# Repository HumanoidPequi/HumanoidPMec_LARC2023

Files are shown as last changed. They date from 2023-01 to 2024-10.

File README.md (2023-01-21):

# Humanoid_LARC2023
Pequi Mecânico - Humanoid soccer LARC 2023

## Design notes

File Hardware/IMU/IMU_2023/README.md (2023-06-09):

# Esquemáticos e informações sobre os IMUS
 As bibliotecas Podem ser encontradas na própria Arduino IDE
- Para o MPU6050: FastIMU
- Para o BNO080: SparkFun BNO080 Cortex Based IMU

## Lembrando que o as pinos padrão da ESP para I2C são:
### D21 - SDA
### D22 - SCL



## Esquemáticos (BNO080 e MPU6050)


# ...[Atenção]...
caso seja encontrado problemas com a utilização do MPU6050, adicione resistores de 10k nos sinais SDA e SCL em configuração pull-up (resistores ligados diretamente no positivo [3.3V] de alimentação)

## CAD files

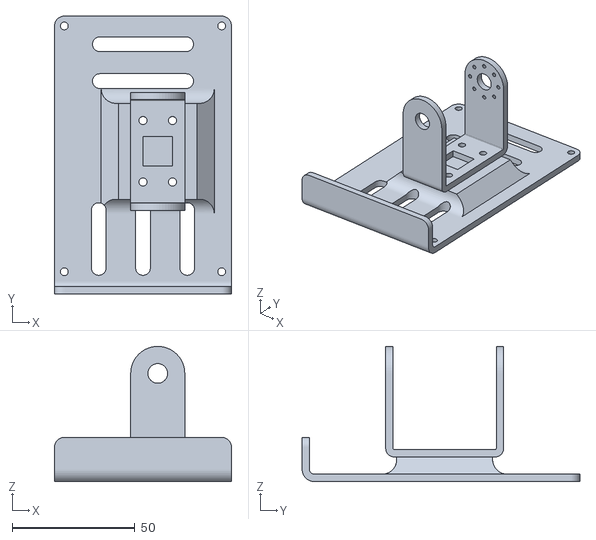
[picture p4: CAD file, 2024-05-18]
Simulação/Martha_ws/src/martha_description/meshes/pe_direito_1.stl
72.0 x 113.0 x 55.0

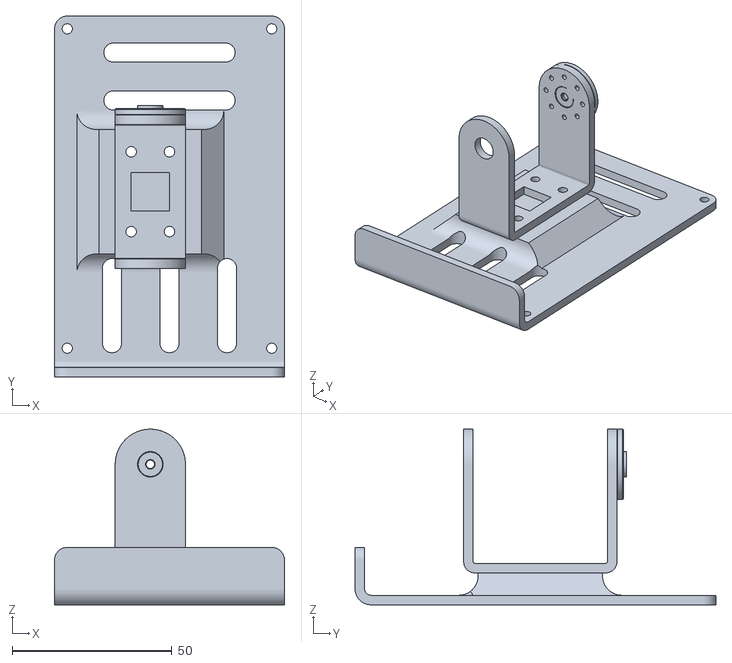
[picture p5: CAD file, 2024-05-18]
Simulação/Martha_ws/src/martha_description/meshes/pe_esquerdo_1.stl
72.0 x 113.0 x 55.0

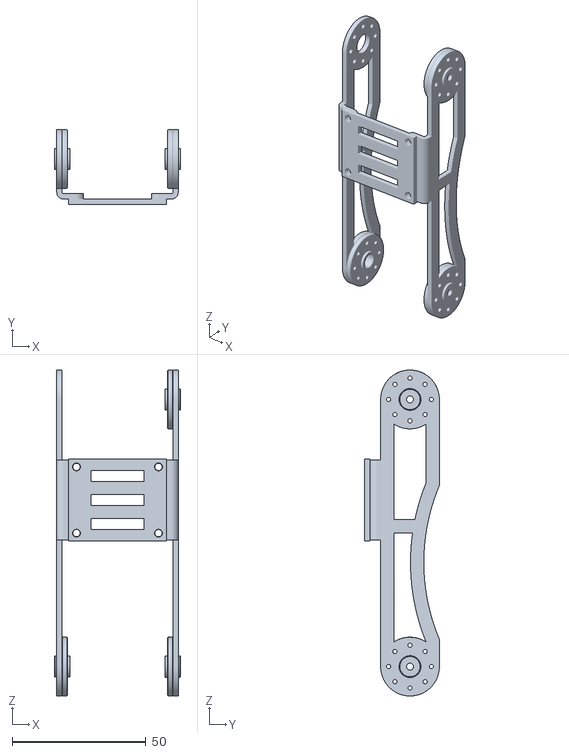
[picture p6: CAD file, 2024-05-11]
Simulação/Martha_ws/src/martha_description/meshes/canela_direita_2_1.stl
47.2 x 28.0 x 122.0

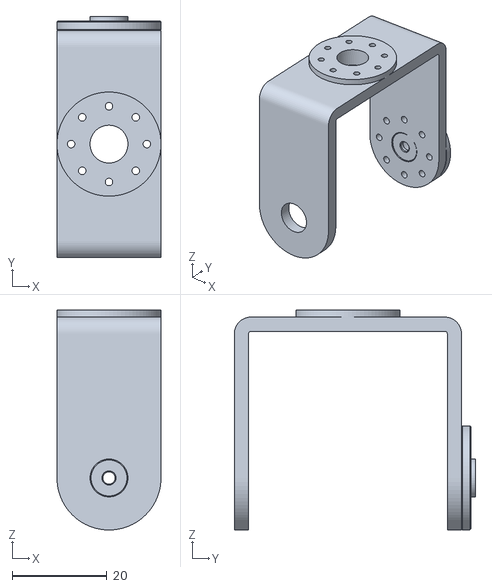
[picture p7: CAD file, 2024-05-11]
Simulação/Martha_ws/src/martha_description/meshes/quadril_direito_1.stl
22.0 x 51.0 x 46.5

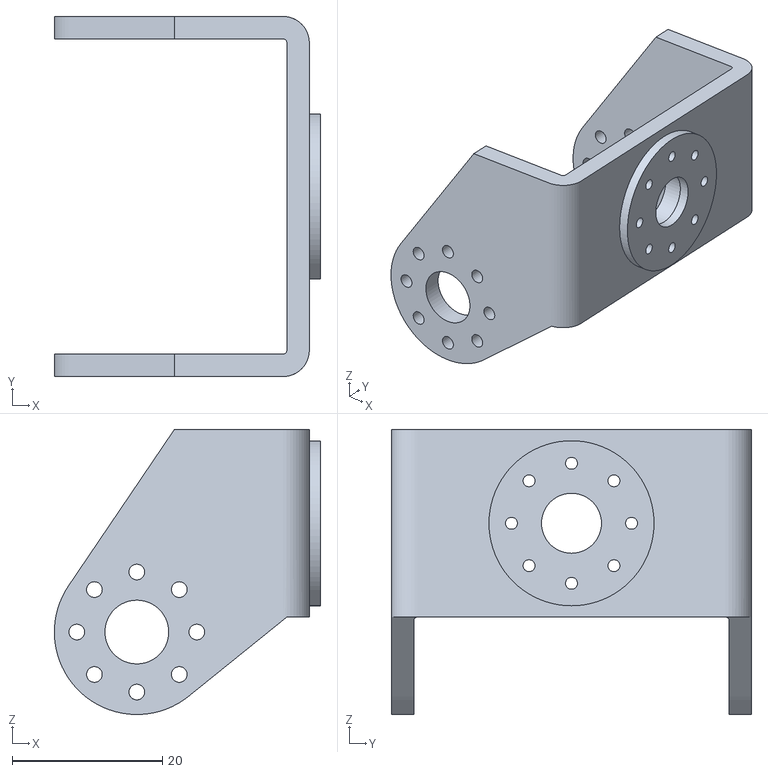
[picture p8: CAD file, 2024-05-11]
Simulação/Martha_ws/src/martha_description/meshes/ombro_direito_1.stl
35.5 x 48.0 x 38.0

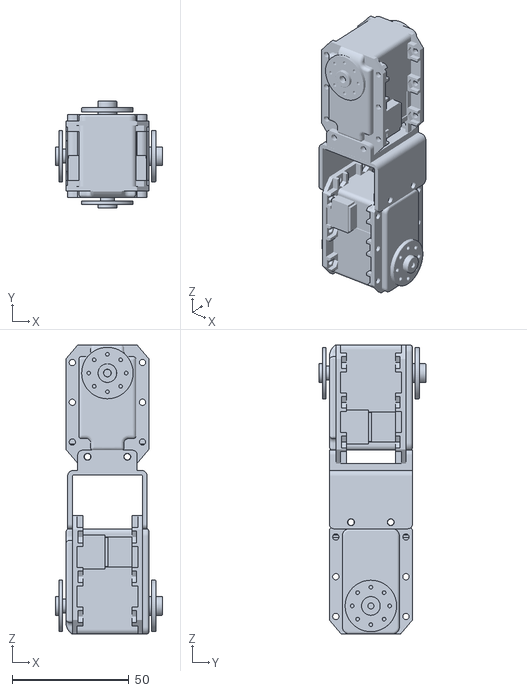
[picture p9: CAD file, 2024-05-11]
Simulação/Martha_ws/src/martha_description/meshes/braco_direito_1.stl
45.8 x 45.9 x 123.6

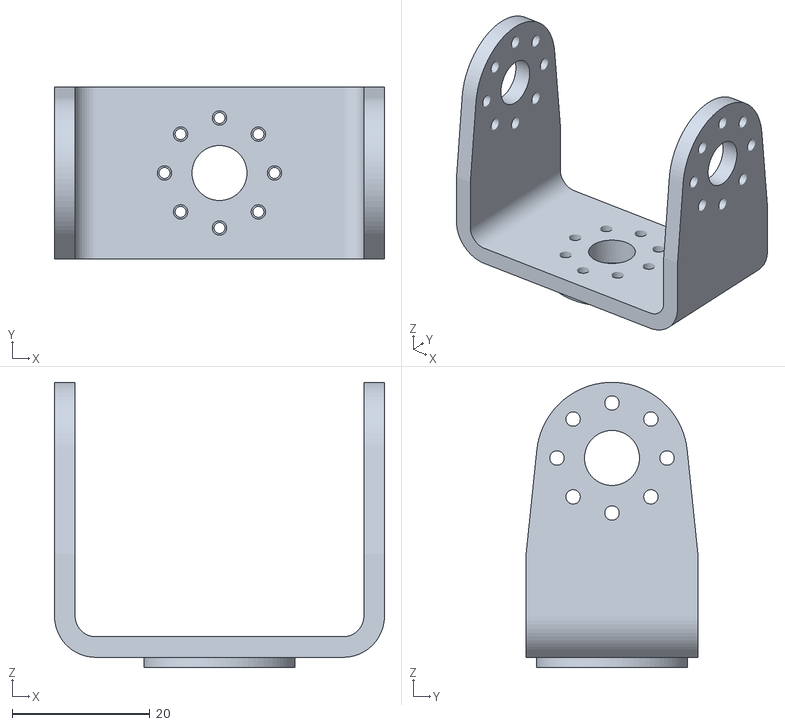
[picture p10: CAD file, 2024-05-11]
Simulação/Martha_ws/src/martha_description/meshes/pescoco_1.stl
48.0 x 25.0 x 41.5

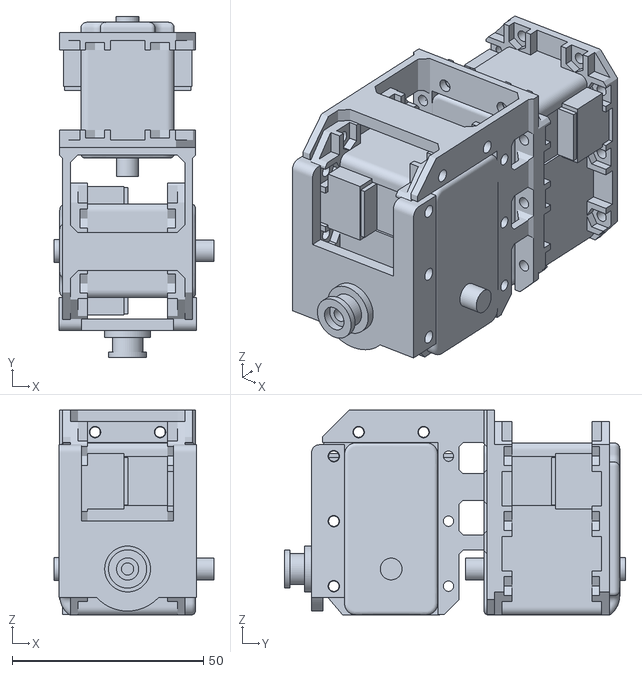
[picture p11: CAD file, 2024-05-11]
Simulação/Martha_ws/src/martha_description/meshes/calcanhar_esquerdo_1.stl
41.8 x 89.2 x 53.5

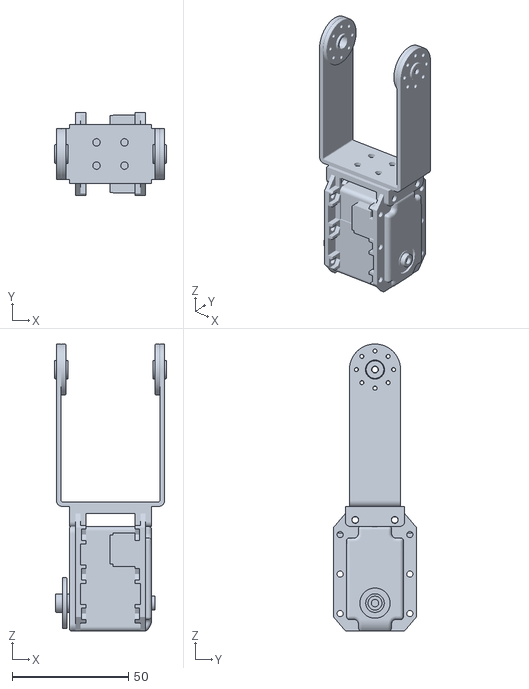
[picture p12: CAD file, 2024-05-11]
Simulação/Martha_ws/src/martha_description/meshes/canela_esquerda_1.stl
48.2 x 35.6 x 123.5

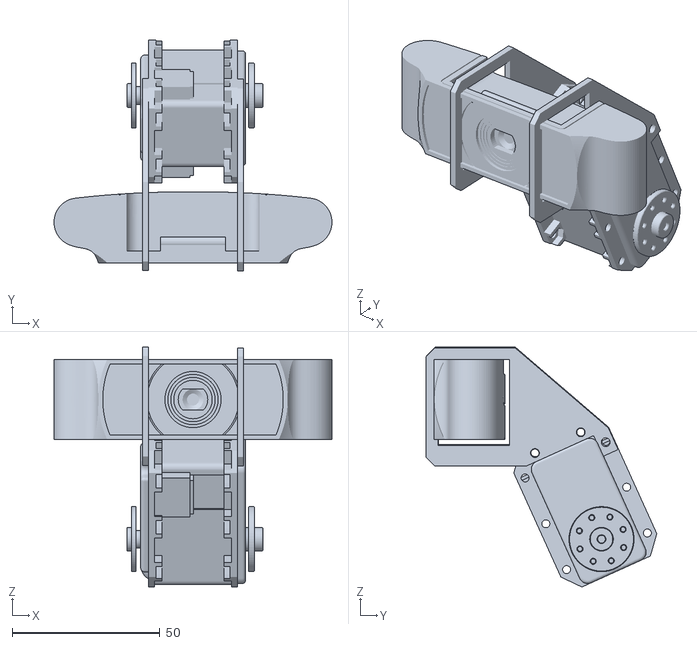
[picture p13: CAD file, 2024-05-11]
Simulação/Martha_ws/src/martha_description/meshes/cabeca_1.stl
94.0 x 78.0 x 81.1

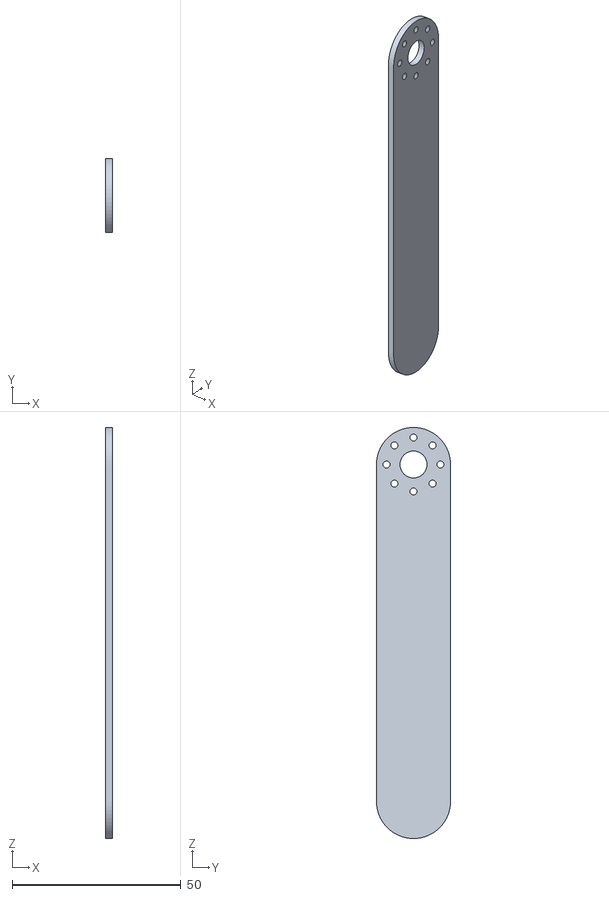
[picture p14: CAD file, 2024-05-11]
Simulação/Martha_ws/src/martha_description/meshes/mao_esquerda_1.stl
2.00 x 22.0 x 122.0

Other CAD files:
Simulação/Martha_ws/src/martha_description/meshes/canela_esquerda_2_1.stl
Simulação/Martha_ws/src/martha_description/meshes/ombro_esquerdo_1.stl
Simulação/Martha_ws/src/martha_description/meshes/braco_esquerdo_1.stl
Simulação/Martha_ws/src/martha_description/meshes/quadril_esquerdo_1.stl
Simulação/Martha_ws/src/martha_description/meshes/canela_direita_1.stl
Simulação/Martha_ws/src/martha_description/meshes/coxa_esquerda_1.stl
Simulação/Martha_ws/src/martha_description/meshes/calcanhar_direito_1.stl
Simulação/Martha_ws/src/martha_description/meshes/coxa_direita_1.stl
Simulação/Martha_ws/src/martha_description/meshes/mao_direita_1.stl

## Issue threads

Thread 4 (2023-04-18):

Ball Tracking

dimitriasilveria, 2023-04-18:

dimitriasilveria, 2023-04-18:
- [ ] Train Yolo object detection
- [ ] Use box coordinates to estimate xy ball position
- [ ] Calculate the necessary angular displacement to align the camera center with the ball
- [ ] Send this angle to the servos via ros
- [ ] Use optical flow to ensure the ball keeps aligned
- [ ] Read head pitch angle from IMU information (via ROS)
- [ ] Distance estimation

dimitriasilveria, 2023-04-23:
<!-- Failed to upload "robocup_book.pdf" -->

dimitriasilveria, 2023-05-06:
@andrecaraiba we need the IMU readings as soon as possible, please

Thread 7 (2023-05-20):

Rosserial

lucasolives, 2023-05-20:

lucasolives, 2023-05-20:
1. Open up terminal and type: `roscore`
2. In a new terminal type: `rosrun rosserial_arduino serial_node.py _port:=/dev/ttyUSB0`
3. Type `rostopic list` to make sure that everything is running

lucasolives, 2023-05-20:
**[ERROR] [1684614705.969329]: Unable to sync with device; possible link problem or link software version mismatch such as hydro rosserial_python with groovy Arduino**

lucasolives, 2023-05-20:
Possible solution:
If rebuilding isn't an option you can add the definitions manually. On the arduino side you'll have a ros_lib folder. You have two sub directories you need to change.

The first is ./ros/node_handle.h. At the top of the file you'll see a few protocol versions defined as const uint8_t. Add in the version id for noetic as const uint8_t PROTOCOL_VER6 = 0xfa; then change the line that states what version should be used. const uint8_t PROTOCOL_VER = PROTOCOL_VER6;.

Lastly, you just need to make this same change in ./ros_lib/ros/node_handle.h

lucasolives, 2023-05-21:
The code **controle_baixo_nível.ino** is being developed, so it has some things that need to be fixed. 1 - `servo_cb()` is able to receive only one angle when it should get two.
Possible solution: Create a `custom_msg` package that contains two UInt16 values.

andrecaraiba, 2023-06-01:
This tutorial solved the problem: https://answers.ros.org/question/394805/esp32-keep-rebooting-with-rosserial/

Closed 2023-06-09.

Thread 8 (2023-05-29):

Trouble with Dynamixel signal

alvinolima50, 2023-05-29:

alvinolima50, 2023-05-29:
What can it be?
The cable impedance is different from the dynamixel input impedance, causing a reflection of the signal interfering with the input signal.

Options to solve the problem: avoid this reflection!

- [ ] level shifter position change
- [ ] Add Diode 5V
- [ ]

andrecaraiba, 2023-06-01:
Possible cause: Incompatibility between the Dynamixel firmware and the Dynamixel2Arduino library. To resolve the issue, it was necessary to change the firmware version from 45 to 40. You can use this reference to update the firmware version by following the steps outlined in Wizard 2.0: [Update firmware version](https://m.youtube.com/watch?v=aVZytXRc_r8).

Additionally, it has been discovered that the signal reflection is actually a return packet containing status information that the Dynamixel returns. You can find more details about this in the [Dynamixel Protocol 1.0 documentation](https://emanual.robotis.com/docs/en/dxl/protocol1/).

Furthermore, for the Dynamixel to function properly, the microcontroller needs to receive these return packet information. This requires a communication circuit between the Dynamixel and the microcontroller. You can refer to the [MX-28 documentation documentation](https://emanual.robotis.com/docs/en/dxl/mx/mx-28/), the circuit is also located in the hardware folder of the repository.

Closed 2023-06-09.

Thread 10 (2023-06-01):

2 Dynamixel strugling to execute different angles

lucasolives, 2023-06-01:

lucasolives, 2023-06-01:
Executing the `codigo_baixo_nivel.ino` in order to send different angles to each dynamixel, the servo was receiving those angles and executed in the first time that i published some data.  In the following publications, the dynamixels stoped to answer the command correctly and made only little movements every time i sent a new angle.

lucasolives, 2023-06-01:
Next questions:
1 - That delay will get us in trouble when the high level is executing by the fact that it stops the program during the time set? Even though it's a small delay?
2 - Apparently there's a function in ros that works kinda like a timer. I didn't go deeper in the subject but the benefit would be that this function wouldn't stop the entire code, but just that process. That way, it would be possible to run another things while the timer is waiting. Is it a better option? (Do some research about `ros::Timer`, `ros::Duration` and the function `now()`)

lucasolives, 2023-06-01:
Structure of ros command to send a UInt16MultiArray type of message(in our case where the topic is servo and we're sending two angles): `rostopic pub servo std_msgs/UInt16MultiArray "data: [**angle1**, **angle2**]"`

Closed 2023-06-09.

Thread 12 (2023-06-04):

Imu

dimitriasilveria, 2023-06-04:

dimitriasilveria, 2023-06-04:
Bno uses I2C protocol. Here is a brief explanation of this protocol: https://www.circuitbasics.com/basics-of-the-i2c-communication-protocol/

dimitriasilveria, 2023-06-04:
esp i2c default pinout: https://randomnerdtutorials.com/esp32-i2c-communication-arduino-ide/#:~:text=When%20using%20the%20ESP32%20with,to%20use%20any%20other%20pins.

dimitriasilveria, 2023-06-04:
bno: https://learn.sparkfun.com/tutorials/qwiic-vr-imu-bno080-hookup-guide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

dimitriasilveria, 2023-06-04:
esp pinout: imagem: https://live.staticflickr.com/4764/40089095211_ec1fee0087_b.jpg

dimitriasilveria, 2023-06-04:
bno hardware description: https://learn.sparkfun.com/tutorials/qwiic-vr-imu-bno080-hookup-guide/all#hardware-assembly

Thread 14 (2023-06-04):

Install ROS jetson tx2

dimitriasilveria, 2023-06-04:
We decide to use ros noetic because we don't have enough knowledge to use microros

dimitriasilveria, 2023-06-04:
Nvidia ros containers: https://github.com/dusty-nv/jetson-containers/tree/master

dimitriasilveria, 2023-06-04:
We could not install ros container because there was no space left on the device. Possible solution:
https://forums.developer.nvidia.com/t/increase-storage-space-of-jetson-tx2-dev-kit-using-sd-card/76872

dimitriasilveria, 2023-06-09:
I am closing this issue because I opened another one in another project

Closed 2023-06-09.

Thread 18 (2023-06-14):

rosserial inside docker container

dimitriasilveria, 2023-06-14:

dimitriasilveria, 2023-06-14:
possible link problem or link software version mismatch such as hydro rosserial_python with groovy Arduino

dimitriasilveria, 2023-06-14:
One possible solution: https://www.hostinger.com.br/tutoriais/arquivo-sudoers

andrecaraiba, 2023-06-15:
possible solution: https://www.homeautomationguy.io/blog/docker-tips/accessing-usb-devices-from-docker-containers

lucasolives, 2023-06-17:
sudo docker build -t teste_ino --build-arg CACHEBUST=$(date +%s) .

sudo docker run -it --privileged -v /dev:/dev --name teste_ino teste_ino bash

lucasolives, 2023-06-19:
Error: Cannot open /dev/ttyUSB0: Permission denied
Solution:
sudo su
//type your password
cd /
cd dev
chown username ttyUSB0

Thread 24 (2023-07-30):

Using two serial ports with esp32

lucasolives, 2023-07-30:

lucasolives, 2023-07-31:
Using the circuit attached to this comment, we tried to use two serial ports in esp32 in order to put one leg on each serial port.

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

Making some tests,

lucasolives, 2023-07-31:
Making some tests, we noticed that esp32 wasn't sending data to both port serials[Serial1(TX0, RX0) e Serial2(TX2, RX2)]. We tried some strategys to solve this problem:

- [ ] Changing HardwareSerial.cpp as the following video told to: [](https://emanual.robotis.com/docs/en/dxl/mx/mx-28/)

- [ ] Use SoftwareSerial with esp32, but aparently it's impossible since esp32 no longer has support to this library.

- [ ] Using the Esp32Software serial. Also didn't work, even though we move uart1 to another pins recommended.

- [ ] Making some research, we found out that esp32 has some gpio's not recommended to use for serial communications, since it's used for flash memory. Aparently, to use uart1, it's necessary the reassignment of pins: [](https://microcontrollerslab.com/esp32-uart-communication-pins-example/) Obs: It's weird, because our esp doesn't have GPIO9 and 10.

- [ ] We found out a repository that changed the dynamixel2arduino library to improve serial communication with esp32 in order to make it easier using 2 serial ports, but also didnt't work: https://github.com/maehem/ESP32-Dynamixel/tree/master

lucasolives, 2023-07-31:
Pinout Esp32:

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

lucasolives, 2023-08-04:
Utilizar preferencialmente as GPIOs:
tx -> 0,2,12,13,14,15,16,17,25,26,27
rx -> 0,2,12,13,14,15,16,17,25,26,27,32,33,34,36,39

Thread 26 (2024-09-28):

Finalização do projeto estrutural

lucasolives, 2024-09-28:
(adicionar @ do marcelo) relatou que a Marta estava com massa discrepante, portanto foi necessário pesar individualmente peças de alumínio.

lucasolives, 2024-09-28:
(adicionar @ do davi aqui) e (adicionar @ do ólives) pesaram componentes. Seguem esses dados:
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
[Página do notion](https://www.notion.so/Pe-as-marcelo-10b21c3dc3788095a0e2e396b4c24415?pvs=4)

lucasolives, 2024-09-28:
Fez-se necessário modelar algumas peças para 3D devido a grande massa das peças, além de ajustar algumas.

- [ ] Inserir insertos em bases genéricas
- [ ] Alterar base da cabeça para 3D
- [ ] Alterar topo da estrurura para 3D
- [ ] Alterar frente inferir para 3D com filamento flexível
- [ ] Alterar peças traseiras para proteger botões

lucasolives, 2024-09-28:
Retiramos estrutura externa da NUC para diminuir o peso geral. Faz-se necessário estrutura 3D para protegê-la na parte superior:
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

- [ ] Criação de estrutura superior da NUC

lucasolives, 2024-09-28:
Para imprimir pé da Marta com tamanho máximo, deve-se se limitar ao valor máximo que esta fómula entregar:
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
onde Hcom é a altura do centro de massa da Marta.

- [ ] Confecção de projeto do pé
- [ ] Definição do centro de massa da Marta
- [ ] Alterar para tamanho adequado
- [ ] Imprimir pé

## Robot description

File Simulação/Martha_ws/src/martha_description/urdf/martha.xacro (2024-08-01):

<?xml version="1.0" ?>
<robot name="martha" xmlns:xacro="http://www.ros.org/wiki/xacro">

<xacro:include filename="$(find martha_description)/urdf/materials.xacro" />
<xacro:include filename="$(find martha_description)/urdf/martha.trans" />
<xacro:include filename="$(find martha_description)/urdf/martha.gazebo" />
<xacro:include filename="$(find martha_description)/urdf/camera.xacro" />
<xacro:include filename="$(find martha_description)/urdf/IMU.xacro" />
<link name="base_link">
  <inertial>
    <origin xyz="-0.00023301230905643097 -0.008767749720889163 0.08499100214486582" rpy="0 0 0"/>
    <mass value="3.42324299"/>
    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
  </inertial>
  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
</link>

<link name="pescoco_1">
  <inertial>
    <origin xyz="-1.9023224968807838e-14 -8.281569874313277e-15 0.011104750965744897" rpy="0 0 0"/>
    <mass value="0.00752807"/>
    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
  </inertial>
  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
</link>

<link name="cabeca_1">
  <inertial>
    <origin xyz="-0.020728139217007956 -0.025090240858054468 0.029326950387914386" rpy="0 0 0"/>
    <mass value="0.16989203"/>
    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
  </inertial>
  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
</link>

<link name="ombro_esquerdo_1">
  <inertial>
    <origin xyz="0.0066866699241785454 2.0816681711721685e-17 -0.0032002556517522762" rpy="0 0 0"/>
    <mass value="0.00784823"/>
    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
  </inertial>
  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
</link>

<link name="ombro_direito_1">
  <inertial>
    <origin xyz="-0.006686669924178101 2.7755575615628914e-17 -0.0032002556517522207" rpy="0 0 0"/>
    <mass value="0.00784823"/>
    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
  </inertial>
  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
</link>

<link name="braco_esquerdo_1">
  <inertial>
    <origin xyz="2.1478896477855614e-05 0.020766946865101756 -0.04944488755371944" rpy="0 0 0"/>
    <mass value="0.24511984"/>
    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
  </inertial>
  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
</link>

<link name="braco_direito_1">
  <inertial>
    <origin xyz="2.1478896478493992e-05 0.02076694686510183 -0.04944488755371926" rpy="0 0 0"/>
    <mass value="0.24511984"/>
    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
  </inertial>
  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
</link>

<link name="mao_esquerda_1">
  <inertial>
    <origin xyz="0.0009999999999996262 1.8780116350924914e-14 -0.051558141367889714" rpy="0 0 0"/>
    <mass value="0.00500432"/>
    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
  </inertial>
  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
</link>

<link name="mao_direita_1">
  <inertial>
    <origin xyz="-0.0009999999999998066 -1.917389857997165e-14 -0.05155814136788935" rpy="0 0 0"/>
    <mass value="0.00500432"/>
    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
  </inertial>
  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
</link>

<link name="quadril_esquerdo_1">
  <inertial>
    <origin xyz="1.4314938123760612e-14 0.001988067036543086 -0.01689495335095707" rpy="0 0 0"/>
    <mass value="0.00770492"/>
    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
  </inertial>
  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
</link>

<link name="coxa_esquerda_1">
  <inertial>
    <origin xyz="1.4332694612498309e-05 -0.0006782563173738359 -0.01214207998264017" rpy="0 0 0"/>
    <mass value="0.09798763"/>
    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
  </inertial>
  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
</link>

<link name="canela_esquerda_2_1">
  <inertial>
    <origin xyz="0.02210055083330358 -0.004367378251287552 -0.05012443509922551" rpy="0 0 0"/>
    <mass value="0.00914336"/>
    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
  </inertial>
  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
</link>

<link name="canela_esquerda_1">
  <inertial>
    <origin xyz="0.0228493411868047 -2.7628101325824495e-09 -0.07781833032204813" rpy="0 0 0"/>
    <mass value="0.05533250"/>
    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
  </inertial>
  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
</link>

<link name="calcanhar_esquerdo_1">
  <inertial>
    <origin xyz="-0.022614332694585237 0.018771743681580518 0.012142498757541087" rpy="0 0 0"/>
    <mass value="0.09643869"/>
    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
  </inertial>
  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
</link>

<link name="pe_esquerdo_1">
  <inertial>
    <origin xyz="0.0034112806849335223 -0.026374357215448188 -0.035772752451398604" rpy="0 0 0"/>
    <mass value="0.04184724"/>
    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
    </inertial>
  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
</link>

<link name="pe_direito_1">
  <inertial>
    <origin xyz="-0.003474406179630303 -0.025760560273646108 -0.03643473231799649" rpy="0 0 0"/>
    <mass value="0.04184724"/>
    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
    </inertial>
  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
</link>

<link name="calcanhar_direito_1">
  <inertial>
    <origin xyz="-0.022614332694585272 0.018771743681580518 0.012142498757541087" rpy="0 0 0"/>
    <mass value="0.09643869"/>
    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
  </inertial>
  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
</link>

<link name="canela_direita_2_1">
  <inertial>
    <origin xyz="0.022100550833303534 -0.004367378251287554 -0.05012443509922543" rpy="0 0 0"/>
    <mass value="0.00914336"/>
    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
  </inertial>
  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
</link>

<link name="canela_direita_1">
  <inertial>
    <origin xyz="0.02284934118680465 -2.76281013778662e-09 -0.07781833032204813" rpy="0 0 0"/>
    <mass value="0.05533250"/>
    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
  </inertial>
  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
</link>

<link name="coxa_direita_1">
  <inertial>
    <origin xyz="1.4332694612477492e-05 -0.0006782563173738359 -0.01214207998264017" rpy="0 0 0"/>
    <mass value="0.09798763"/>
    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
  </inertial>
  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
</link>


<link name="quadril_direito_1">
  <inertial>
    <origin xyz="1.4287182548144983e-14 0.0019880670365430807 -0.016894953350957066" rpy="0 0 0"/>
    <mass value="0.00770492"/>
    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
  </inertial>
  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
</link>

<joint name="pescoco_rZ" type="revolute">
  <origin xyz="0.0 -0.0114 0.191473" rpy="0 0 0"/>
  <parent link="base_link"/>
  <child link="pescoco_1"/>
  <axis xyz="-0.0 -0.0 1.0"/>
  <limit lower="-3.14159" upper="3.14159" effort="1000.0" velocity="0.01"/>
</joint>

<joint name="cabeca_rX" type="revolute">
  <origin xyz="0.021 0.0 0.029" rpy="0 0 0"/>
  <parent link="pescoco_1"/>
  <child link="cabeca_1"/>
  <axis xyz="1.0 -0.0 0.0"/>
  <limit lower="-3.14159" upper="3.14159" effort="1000.0" velocity="0.01"/>
</joint>

<joint name="ombro_esquerdo_rX" type="continuous">
  <origin xyz="0.0771 -0.01 0.16273" rpy="0 0 0"/>
  <parent link="base_link"/>
  <child link="ombro_esquerdo_1"/>
  <axis xyz="1.0 0.0 -0.0"/>
  <limit effort="1000.0" velocity="0.01"/>
</joint>

<joint name="ombro_direito_rX" type="continuous">
  <origin xyz="-0.0771 -0.01 0.16273" rpy="0 0 0"/>
  <parent link="base_link"/>
  <child link="ombro_direito_1"/>
  <axis xyz="-1.0 -0.0 0.0"/>
  <limit effort="1000.0" velocity="0.01"/>
</joint>

<joint name="ombro_esquerdo_rY" type="revolute">
  <origin xyz="0.02 -0.021 -0.0145" rpy="0 0 0"/>
  <parent link="ombro_esquerdo_1"/>
  <child link="braco_esquerdo_1"/>
  <axis xyz="0.0 -1.0 0.0"/>
  <limit lower="-3.14159" upper="3.14159" effort="1000.0" velocity="0.01"/>
</joint>

<joint name="ombro_direito_rY" type="revolute">
  <origin xyz="-0.02 -0.021 -0.0145" rpy="0 0 0"/>
  <parent link="ombro_direito_1"/>
  <child link="braco_direito_1"/>
  <axis xyz="0.0 -1.0 -0.0"/>
  <limit lower="-3.14159" upper="3.14159" effort="1000.0" velocity="0.01"/>
</joint>

<joint name="mao_esquerda" type="revolute">
  <origin xyz="0.02075 0.02074 -0.0996" rpy="0 0 0"/>
  <parent link="braco_esquerdo_1"/>
  <child link="mao_esquerda_1"/>
  <axis xyz="1.0 0.0 -0.0"/>
  <limit lower="-3.14159" upper="3.14159" effort="1000.0" velocity="0.01"/>
</joint>

<joint name="mao_direita" type="revolute">
  <origin xyz="-0.02075 0.02074 -0.0996" rpy="0 0 0"/>
  <parent link="braco_direito_1"/>
  <child link="mao_direita_1"/>
  <axis xyz="1.0 0.0 -0.0"/>
  <limit lower="-3.14159" upper="3.14159" effort="1000.0" velocity="0.01"/>
</joint>

<joint name="quadril_esquerdo_rZ" type="revolute">
  <origin xyz="0.04 -0.01 -0.0044" rpy="0 0 0"/>
  <parent link="base_link"/>
  <child link="quadril_esquerdo_1"/>
  <axis xyz="0.0 0.0 -1.0"/>
  <limit lower="-3.14159" upper="3.14159" effort="1000.0" velocity="0.01"/>
</joint>

<joint name="quadril_esquerdo_rY" type="revolute">
  <origin xyz="0.0 0.02215 -0.0355" rpy="0 0 0"/>
  <parent link="quadril_esquerdo_1"/>
  <child link="coxa_esquerda_1"/>
  <axis xyz="0.0 -1.0 -0.0"/>
  <limit lower="-3.14159" upper="3.14159" effort="1000.0" velocity="0.01"/>
</joint>

<joint name="joelho_esquerdo_rX" type="revolute">
  <origin xyz="0.00235 0.0 -0.1005" rpy="0 0 0"/>
  <parent link="canela_esquerda_1"/>
  <child link="canela_esquerda_2_1"/>
  <axis xyz="-1.0 -0.0 -0.0"/>
  <limit lower="-3.14159" upper="3.14159" effort="1000.0" velocity="0.01"/>
</joint>
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

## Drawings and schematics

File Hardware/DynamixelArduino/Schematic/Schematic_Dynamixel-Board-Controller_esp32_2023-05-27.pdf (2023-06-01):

A | A

1

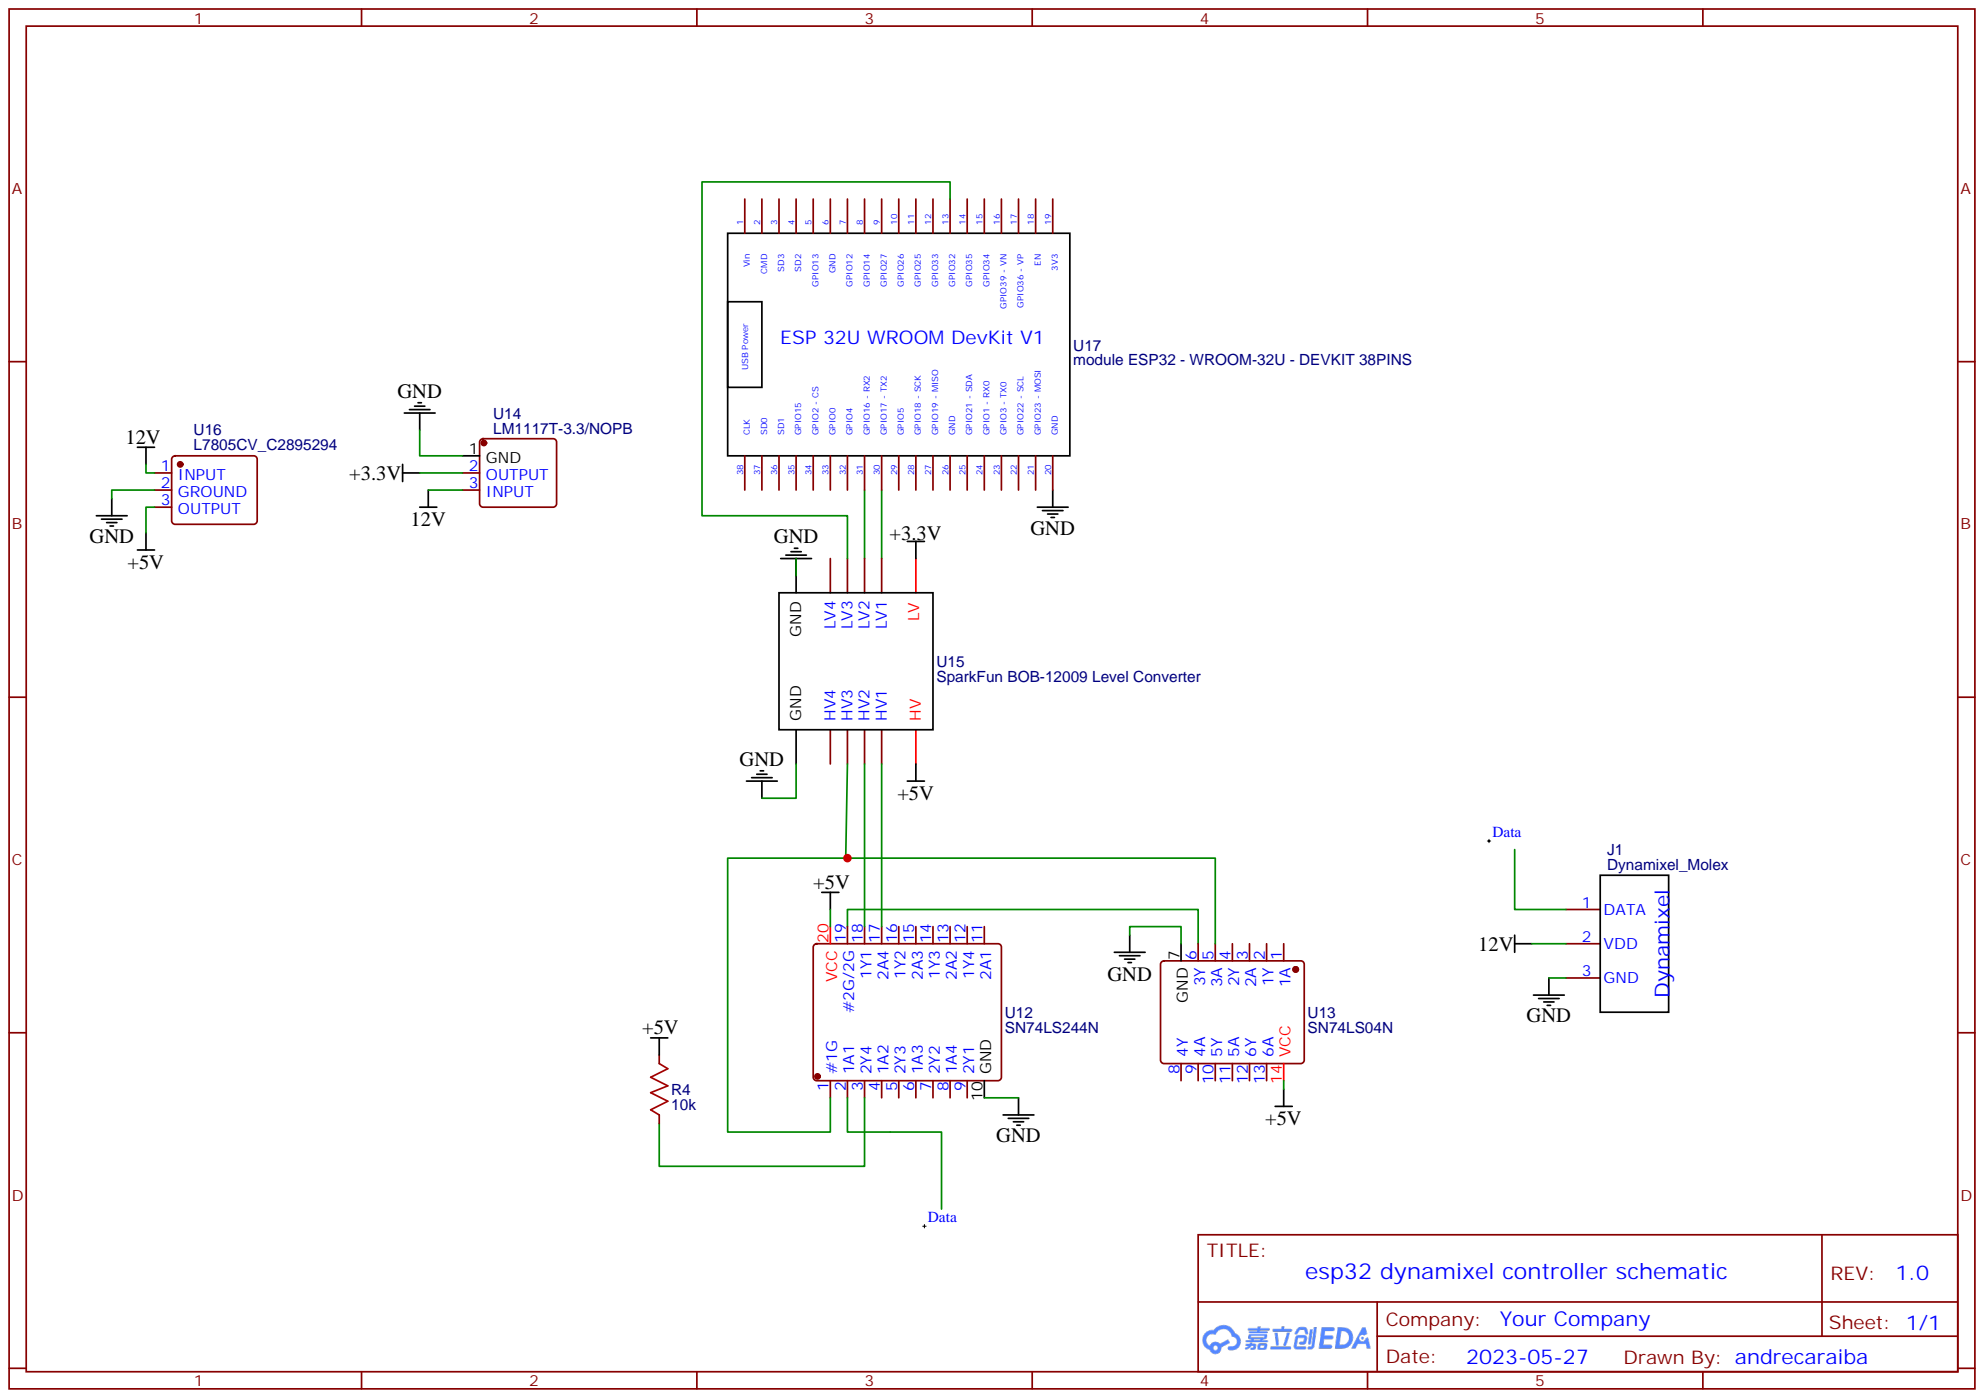
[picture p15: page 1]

SparkFun BOB-12009 Level Converter

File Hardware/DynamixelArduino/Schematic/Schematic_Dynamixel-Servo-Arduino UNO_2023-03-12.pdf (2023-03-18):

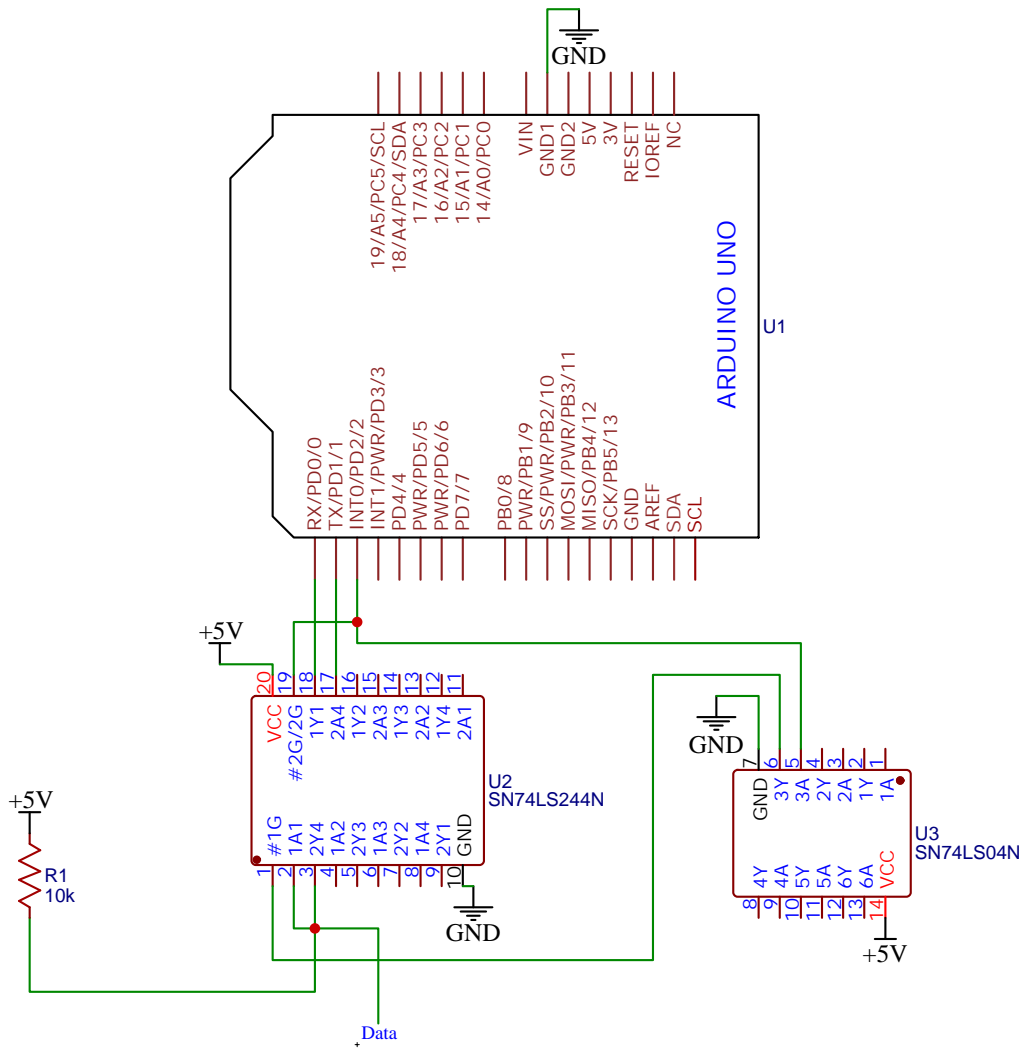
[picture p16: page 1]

Company: Pequi Mec nico

Drawn By: Andr Caraiba

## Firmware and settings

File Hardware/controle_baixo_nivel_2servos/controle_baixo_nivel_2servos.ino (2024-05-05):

#include <ros.h>

//Dynamixel library
#include <Dynamixel2Arduino.h>

//Ros stuff(dynamixel, mpu e bno)
#include <ros/time.h>
#include <std_msgs/Int16MultiArray.h>
#include <std_msgs/Header.h>
#include <sensor_msgs/Imu.h>
#include <geometry_msgs/Quaternion.h>
#include <geometry_msgs/Vector3.h>

//Hardware specifications
#include <ArduinoHardware.h>
#define DXL_SERIAL Serial2
#define JOINTS_TOTAL 20
const int DXL_DIR_PIN = 13; // DYNAMIXEL Shield DIR PIN
const uint8_t DXL_ID_CNT = 14;
const uint8_t DXL_ID_LIST[JOINTS_TOTAL] = {1, 2, 3, 4, 5, 6, 7, 8, 9, 10, 11, 12 , 13, 14, 15, 16, 17, 18, 19, 20};
const uint8_t ball_tracking[DXL_ID_CNT] = {1,2,3,4,5,6,7,8,9,10,11,12,19,20};
const uint8_t ID_HEAD[DXL_ID_CNT] = {19, 20};
const uint8_t ID_RIGHT_LEG[DXL_ID_CNT] = {1, 2, 3, 4, 5, 6};
//const uint8_t ID_LEFT_LEG[DXL_ID_CNT] = {7, 8, 9, 10, 11, 12};
//const uint8_t ID_RIGHT_ARM[DXL_ID_CNT] = {13, 14, 15};
//const uint8_t ID_RIGHT_ARM[DXL_ID_CNT] = {16, 17, 18};
const float DXL_PROTOCOL_VERSION = 1.0;

//Imu(BNO080) stuff
#include <Wire.h>
#include "SparkFun_BNO080_Arduino_Library.h"
BNO080 myIMU;
//Imu(mpu)
#include "FastIMU.h"
#include "Madgwick.h"

#define IMU_ADDRESS 0x68    //Change to the address of the IMU
#define PERFORM_CALIBRATION //Comment to disable startup calibration
MPU6050 IMU;               //Change to the name of any supported IMU!

calData calib = { 0 };  //Calibration data
AccelData IMUAccel;    //Sensor data
GyroData IMUGyro;
MagData IMUMag;
Madgwick filter;

//Define led
#define blinkPin 2

const uint8_t head[DXL_ID_CNT] = {180, 180};
const uint8_t right_leg[DXL_ID_CNT] = {180, 88, 180, 200, 202, 72};
const uint8_t left_leg[DXL_ID_CNT] = {180, 180, 180, 180, 180, 180};
const uint8_t right_arm[DXL_ID_CNT] = {180, 180, 180};
const uint8_t left_arm[DXL_ID_CNT] = {180, 180, 180};
const uint8_t tracking_position[DXL_ID_CNT] = {180, 88, 180, 200, 202, 72, 180, 180, 180, 180, 180, 180, 180, 180};
//const uint8_t marta[DXL_ID_CNT] = {180, 180, 180, 180, 180, 180, 180, 180, 180, 180, 180, 180, 180, 180, 180, 180, 180, 180, 180, 180};
//const uint8_t max_pos[DXL_ID_CNT] = {360, 360, 360, 360, 360, 360, 360, 360, 360, 360, 360, 360, 360, 360, 360, 360, 360, 360, 360, 360};
//const uint8_t min_pos[DXL_ID_CNT] = {0, 0, 0, 0, 0, 0, 0, 0, 0, 0, 0, 0, 0, 0, 0, 0, 0, 0, 0, 0};

Dynamixel2Arduino dxl(DXL_SERIAL, DXL_DIR_PIN);

ros::NodeHandle nh;

//Imu ros configs
sensor_msgs::Imu inertial;
geometry_msgs::Vector3 lin;
geometry_msgs::Vector3 ang;

//Imu(bno) ros configs
ros::Publisher bno("imu/BNO", &inertial);
char imu_bno[] = "/bno";

//Imu(mpu) ros configs
ros::Publisher mpu("imu/MPU", &inertial);
char imu_mpu[] = "/mpu";

void servo_cb(const std_msgs::Int16MultiArray& cmd_msg) {
  if (cmd_msg.data_length != DXL_ID_CNT) {
    return;
  }

  for (int i = 0; i < DXL_ID_CNT; i++) {
    dxl.setGoalPosition(ball_tracking[i], tracking_position[i] + cmd_msg.data[i], UNIT_DEGREE);
    delay(0.1);
  }
}

ros::Subscriber<std_msgs::Int16MultiArray> sub("servo", servo_cb);

void setup() {
  //Dynamixel setup
  Serial.begin(57600);
  dxl.begin(1000000);
  nh.initNode();
  nh.subscribe(sub);

  dxl.setPortProtocolVersion(DXL_PROTOCOL_VERSION);

  for (int i = 0; i < DXL_ID_CNT; i++) {
    dxl.ping(DXL_ID_LIST[i]);
    dxl.torqueOff(DXL_ID_LIST[i]);
    dxl.setOperatingMode(DXL_ID_LIST[i], OP_POSITION);
    dxl.torqueOn(DXL_ID_LIST[i]);
  }

  for (int i = 0; i < DXL_ID_CNT; i++) {
    dxl.setGoalPosition(ball_tracking[i], tracking_position[i], UNIT_DEGREE);
    delay(0.1);
  }
  
  //Imu(bno) setup
  pinMode(blinkPin, OUTPUT);
  Wire.begin();
  digitalWrite(blinkPin, LOW);
  if (myIMU.begin() == false)
  {
    digitalWrite(blinkPin, HIGH);
    delay(1000);
    digitalWrite(blinkPin, LOW);
    delay(1000);
    digitalWrite(blinkPin, HIGH);
    while (1);
  }
  delay(10);
  Wire.setClock(400000); // Increase I2C data rate to 400kHz
  delay(10);
  myIMU.enableLinearAccelerometer(8); // m/s^2 no gravity
  myIMU.enableRotationVector(4);      // quat
  myIMU.enableGyro(12);               // rad/s
  nh.advertise(bno);

  digitalWrite(blinkPin, LOW);

  //Imu(mpu) setup
  delay(1);
  Wire.begin();
  Wire.setClock(400000); //400khz clock

  Serial.begin(57600);
  while (!Serial) {
    ;
  }

  int err = IMU.init(calib, IMU_ADDRESS);
  if (err != 0) {
    Serial.print("Error initializing IMU: ");
    Serial.println(err);
    while (true) {
      ;
    }
  }

  if (err != 0) {
    Serial.print("Error Setting range: ");
    Serial.println(err);
    while (true) {
      ;
    }
  }

#ifdef PERFORM_CALIBRATION
  Serial.println("FastIMU Calibrated Quaternion example");
  if (IMU.hasMagnetometer()) {
    delay(1000);
    Serial.println("Move IMU in figure 8 pattern until done.");
    delay(3000);
    IMU.calibrateMag(&calib);
    Serial.println("Magnetic calibration done!");
  }
  else {
    delay(1000);
  }
  Serial.println("Keep IMU level.");
  delay(5000);
  IMU.calibrateAccelGyro(&calib);
  Serial.println("Calibration done!");
  Serial.println("Accel biases X/Y/Z: ");
  Serial.print(calib.accelBias[0]);
  Serial.print(", ");
  Serial.print(calib.accelBias[1]);
  Serial.print(", ");
  Serial.println(calib.accelBias[2]);
  Serial.println("Gyro biases X/Y/Z: ");
  Serial.print(calib.gyroBias[0]);
  Serial.print(", ");
  Serial.print(calib.gyroBias[1]);
  Serial.print(", ");
  Serial.println(calib.gyroBias[2]);
  if (IMU.hasMagnetometer()) {
    Serial.println("Mag biases X/Y/Z: ");
    Serial.print(calib.magBias[0]);
    Serial.print(", ");
    Serial.print(calib.magBias[1]);
    Serial.print(", ");
    Serial.println(calib.magBias[2]);
    Serial.println("Mag Scale X/Y/Z: ");
    Serial.print(calib.magScale[0]);
    Serial.print(", ");
    Serial.print(calib.magScale[1]);
    Serial.print(", ");
    Serial.println(calib.magScale[2]);
  }
  delay(5000);
  IMU.init(calib, IMU_ADDRESS);

  filter.begin(0.2f);
#endif
  nh.advertise(mpu);
} 

void loop() {
  nh.spinOnce();
   
  //Imu(bno) loop
  inertial.header.frame_id = imu_bno;
  inertial.header.stamp = nh.now();
  if (myIMU.dataAvailable() == true)
  {
    digitalWrite(blinkPin, HIGH);
    // internal copies of the IMU data
    byte linAccuracy = 0;
    byte gyroAccuracy = 0;
    float quatRadianAccuracy = 0;
    byte quatAccuracy = 0;

    // get IMU data in one go for each sensor type
    myIMU.getLinAccel(lin.x, lin.y, lin.z, linAccuracy);
    myIMU.getGyro(ang.x, ang.y, ang.z, gyroAccuracy);
    myIMU.getQuat(inertial.orientation.x, inertial.orientation.y, inertial.orientation.z, inertial.orientation.w, quatRadianAccuracy, quatAccuracy);
    inertial.angular_velocity = ang;
    inertial.linear_acceleration = lin;
    bno.publish(&inertial);
    digitalWrite(blinkPin, LOW);
  }
  bno.publish(&inertial);
  delay(1);

  //Imu(mpu) loop
  inertial.header.frame_id = imu_mpu;
  inertial.header.stamp = nh.now();

IMU.update();
  IMU.getAccel(&IMUAccel);
  IMU.getGyro(&IMUGyro);
  if (IMU.hasMagnetometer()) {
    IMU.getMag(&IMUMag);
    filter.update(IMUGyro.gyroX, IMUGyro.gyroY, IMUGyro.gyroZ, IMUAccel.accelX, IMUAccel.accelY, IMUAccel.accelZ, IMUMag.magX, IMUMag.magY, IMUMag.magZ);
  }
  else {
    filter.updateIMU(IMUGyro.gyroX, IMUGyro.gyroY, IMUGyro.gyroZ, IMUAccel.accelX, IMUAccel.accelY, IMUAccel.accelZ);
  }
  Serial.print("QW: ");
  Serial.print(filter.getQuatW());
  Serial.print("\tQX: ");
  Serial.print(filter.getQuatX());
  Serial.print("\tQY: ");
  Serial.print(filter.getQuatY());
  Serial.print("\tQZ: ");
  Serial.print(filter.getQuatZ());

  IMU.getAccel(&IMUAccel);
  Serial.print("\taccX: ");
  Serial.print(IMUAccel.accelX);
  Serial.print("\taccY");
  Serial.print(IMUAccel.accelY);
  Serial.print("\taccZ");
  Serial.print(IMUAccel.accelZ);
  
  IMU.getGyro(&IMUGyro);
  Serial.print("\tgyroX");
  Serial.print(IMUGyro.gyroX);
  Serial.print("\tgyroY");
  Serial.print(IMUGyro.gyroY);
  Serial.print("\tgyroZ");
  Serial.println(IMUGyro.gyroZ);
  
    ang.x = IMUAccel.accelX;
    ang.y = IMUAccel.accelY;
    ang.z = IMUAccel.accelZ;

    lin.x = IMUGyro.gyroX;
    lin.y = IMUGyro.gyroY;
    lin.z = IMUGyro.gyroZ;

    inertial.angular_velocity = ang;
    inertial.linear_acceleration = lin;
    
    inertial.orientation.x = filter.getQuatX();
    inertial.orientation.y = filter.getQuatY();
    inertial.orientation.z = filter.getQuatZ();
    inertial.orientation.w = filter.getQuatW();

    mpu.publish(&inertial);
  mpu.publish(&inertial);
  delay(1);
  
  //keep sending the latest angle to dynamixel
  set_position();
}

void set_position(){
  for (int i = 0; i < DXL_ID_CNT; i++) {
    dxl.setGoalPosition(ball_tracking[i], tracking_position[i], UNIT_DEGREE);
    delay(0.1);
  }
}

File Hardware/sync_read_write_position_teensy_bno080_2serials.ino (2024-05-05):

#include <Dynamixel2Arduino.h>
#include <Wire.h>
#include "SparkFun_BNO080_Arduino_Library.h"

#include <ros.h>
#include <std_msgs/Int16MultiArray.h>
#include <ros/time.h>
#include <std_msgs/Header.h>
#include <sensor_msgs/Imu.h>
#include <geometry_msgs/Quaternion.h>
#include <geometry_msgs/Vector3.h>

// Please modify it to suit your hardware.
#define DEBUG_SERIAL Serial
#define DXL_SERIAL1 Serial1
#define DXL_SERIAL2 Serial2
#define DXL_SERIAL3 Serial3
#define DXL_SERIAL5 Serial5

#define blinkPin 13

const int DXL_DIR_PIN1 = 2; // pino de controle Serial1
const int DXL_DIR_PIN2 = 9; // pino de controle Serial2
const int DXL_DIR_PIN3 = 23; // pino de controle Serial3
const int DXL_DIR_PIN5 = 22; // pino de controle Serial5

ros::NodeHandle nh;

sensor_msgs::Imu inertial;
geometry_msgs::Vector3 lin;
geometry_msgs::Vector3 ang;
ros::Publisher pub("micro/IMU", &inertial);
char in[] = "/imu";

Dynamixel2Arduino dxl1(DXL_SERIAL1, DXL_DIR_PIN1); //Perna direita
Dynamixel2Arduino dxl2(DXL_SERIAL2, DXL_DIR_PIN2); //Perna esquerda
Dynamixel2Arduino dxl3(DXL_SERIAL3, DXL_DIR_PIN3); //Perna esquerda
Dynamixel2Arduino dxl5(DXL_SERIAL5, DXL_DIR_PIN5); //Perna direita

BNO080 myIMU;

const uint8_t BROADCAST_ID = 254;
const float DYNAMIXEL_PROTOCOL_VERSION = 1.0;
const uint8_t DXL_ID_CNT = 6;
const uint8_t DXL_ID_CNT_12 = 12;
//const uint8_t DXL_ID_LIST[DXL_ID_CNT] = {15, 18}; //braços
//const uint8_t DXL_ID_LIST[DXL_ID_CNT] = {1, 2, 3, 4, 5, 6}; //perna direita
const uint8_t DXL_ID_LIST[DXL_ID_CNT_12] = {1, 2, 3, 4, 5, 6, 7, 8, 9, 10, 11, 12};
const uint8_t DXL_ID_LIST_L[DXL_ID_CNT] = {6, 8, 9, 10, 11, 12}; //perna esquerda
const uint16_t user_pkt_buf_cap = 128;
uint8_t user_pkt_buf[user_pkt_buf_cap];

// Starting address of the Data to read; Present Position = 132
const uint16_t SR_START_ADDR = 38;
// Length of the Data to read; Length of Position data of X series is 4 byte
const uint16_t SR_ADDR_LEN = 2;
// Starting address of the Data to write; Goal Position = 116
const uint16_t SW_START_ADDR = 30;
// Length of the Data to write; Length of Position data of X series is 4 byte
const uint16_t SW_ADDR_LEN = 2;
typedef struct sr_data{
  int32_t present_position;
} __attribute__((packed)) sr_data_t;
typedef struct sw_data{
  int32_t goal_position;
} __attribute__((packed)) sw_data_t;

/*
typedef struct sw_data1{
  int32_t goal_position1;
} __attribute__((packed)) sw_data_t1;
*/

sr_data_t sr_data[DXL_ID_CNT];
DYNAMIXEL::InfoSyncReadInst_t sr_infos;
DYNAMIXEL::XELInfoSyncRead_t info_xels_sr[DXL_ID_CNT];

sw_data_t sw_data1[DXL_ID_CNT];
sw_data_t sw_data2[DXL_ID_CNT];
DYNAMIXEL::InfoSyncWriteInst_t sw_infos1;
DYNAMIXEL::InfoSyncWriteInst_t sw_infos2;
DYNAMIXEL::XELInfoSyncWrite_t info_xels_sw1[DXL_ID_CNT];
DYNAMIXEL::XELInfoSyncWrite_t info_xels_sw2[DXL_ID_CNT];

//This namespace is required to use DYNAMIXEL Control table item name definitions
using namespace ControlTableItem;

int32_t goal_position[DXL_ID_CNT_12] = {        856, 1820, 2048, 2048, 1024, 2048,     2048, 2048, 2048, 2048, 2048, 1593};
int32_t goal_position_initial[DXL_ID_CNT_12] = {856, 1820, 2048, 2048, 1024, 2048,     2048, 2048, 2048, 2048, 2048, 1593};
int32_t goal_position1[DXL_ID_CNT_12] = {856, 1820, 2048, 2048, 1024, 2048,     2048, 2048, 2048, 2048, 2048, 1593};

void servo_cb(const std_msgs::Int16MultiArray& cmd_msg){
  for(int i; i < DXL_ID_CNT; i++){
  goal_position[i] = goal_position_initial[i] + cmd_msg.data[i];
  }
}

ros::Subscriber<std_msgs::Int16MultiArray> sub("servo", servo_cb);

void setup() {
  nh.initNode();
  nh.subscribe(sub);
  
  bno_setup();
  
  uint8_t i;
  pinMode(LED_BUILTIN, OUTPUT);
  DEBUG_SERIAL.begin(1000000);
  dxl1.begin(1000000);
  dxl2.begin(1000000);
  
  dxl1.setPortProtocolVersion(DYNAMIXEL_PROTOCOL_VERSION);
  dxl2.setPortProtocolVersion(DYNAMIXEL_PROTOCOL_VERSION);

// Prepare the SyncRead structure
  for(i = 0; i < DXL_ID_CNT; i++){
    dxl1.torqueOff(DXL_ID_LIST[i]);
    dxl1.setOperatingMode(DXL_ID_LIST[i], OP_POSITION);
  }
  for(i = 6; i < DXL_ID_CNT_12; i++){
    dxl2.torqueOff(DXL_ID_LIST[i]);
    dxl2.setOperatingMode(DXL_ID_LIST[i], OP_POSITION);
  }
  dxl1.torqueOn(BROADCAST_ID);
  dxl2.torqueOn(BROADCAST_ID);

  // Fill the members of structure to syncRead using external user packet buffer
  sr_infos.packet.p_buf = user_pkt_buf;
  sr_infos.packet.buf_capacity = user_pkt_buf_cap;
  sr_infos.packet.is_completed = false;
  sr_infos.addr = SR_START_ADDR;
  sr_infos.addr_length = SR_ADDR_LEN;
  sr_infos.p_xels = info_xels_sr;
  sr_infos.xel_count = 0;  

  for(i = 0; i < DXL_ID_CNT; i++){
    info_xels_sr[i].id = DXL_ID_LIST[i];
    info_xels_sr[i].p_recv_buf = (uint8_t*)&sr_data[i];
    sr_infos.xel_count++;
  }
  sr_infos.is_info_changed = true;

  // Fill the members of structure to syncWrite using internal packet buffer
  sw_infos1.packet.p_buf = nullptr;
  sw_infos1.packet.is_completed = false;
  sw_infos1.addr = SW_START_ADDR;
  sw_infos1.addr_length = SW_ADDR_LEN;
  sw_infos1.p_xels = info_xels_sw1;
  sw_infos1.xel_count = 0;

  for(i = 0; i < DXL_ID_CNT; i++){
    info_xels_sw1[i].id = DXL_ID_LIST[i];
    info_xels_sw1[i].p_data = (uint8_t*)&sw_data1[i].goal_position;
    sw_infos1.xel_count++;
  }

  sw_infos1.is_info_changed = true;

 
  sw_infos2.packet.p_buf = nullptr;
  sw_infos2.packet.is_completed = false;
  sw_infos2.addr = SW_START_ADDR;
  sw_infos2.addr_length = SW_ADDR_LEN;
  sw_infos2.p_xels = info_xels_sw2;
  sw_infos2.xel_count = 0;

  
  for(i = 6; i < DXL_ID_CNT_12; i++){
    info_xels_sw2[i].id = DXL_ID_LIST[i];
    info_xels_sw2[i].p_data = (uint8_t*)&sw_data2[i].goal_position;
    sw_infos2.xel_count++;
  }
  
  sw_infos2.is_info_changed = true;

}

void loop() {
  nh.spinOnce();
  // put your main code here, to run repeatedly:
  static uint32_t try_count = 0;
  uint8_t i, recv_cnt;
  
  // Insert a new Goal Position to the SyncWrite Packet
  for(i = 0; i < DXL_ID_CNT; i++){
    nh.spinOnce();
    sw_data1[i].goal_position = goal_position[i];
  }
  sw_infos1.is_info_changed = true;
  dxl1.syncWrite(&sw_infos1);

  delay(1);

  for(i = 6; i < DXL_ID_CNT_12; i++){
    nh.spinOnce();
    sw_data2[i].goal_position = goal_position_initial[i];
  }
  
  // Update the SyncWrite packet status
  sw_infos2.is_info_changed = true;
  dxl2.syncWrite(&sw_infos2); 
 
 
  /*DEBUG_SERIAL.print("Serial 1:");
  DEBUG_SERIAL.println(dxl1.syncWrite(&sw_infos1));
  //delayMicroseconds(250);
  DEBUG_SERIAL.print("Serial 2:");
  DEBUG_SERIAL.println(dxl2.syncWrite(&sw_infos2));*/
  
  bno_loop();
  
  delayMicroseconds(250);
//  for(i = 0; i < 50001; i++){
//    ;
//  }
}
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

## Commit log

2022-12-28 Add files via upload
    Controle de baixo nível - Humanoid Marta
2023-01-21 Add files via upload
    controle de baixo nível
2023-03-18 Adcionado arquivos iniciais para a solução alternativa dos servos
2023-05-21 Add files via upload
    This code is being developed, so it has some things that need to be fixed.
    1 - servo_cb is able to receive only one angle when it should get two.
    Possible solution: Create a custom_msg package that contains two UInt16 values.
    (yes, the code is very messy)
    [controle_baixo_nivel.ino]
2023-06-01 Added Schematic for communication between esp32 and dynamixel
2023-06-04 Adição de códigos mais recentes dos IMUS (BNO080 e MPU6050) funcionando com Rosserial
2023-06-04 Update README.md
    Esquemáticos e informações sobre os IMUs
2023-09-10 Add syncwrite for 4 serials with constraint joints
2023-09-10 Add angle limits and joint reversed
    [syncwrte_4_serial_ros_simples_angles_constraints.ino]
2024-05-05 Criando a base da simulação da Marta
    [MAO_v1_1.stl, MAO_v1__1__1.stl, braco_v4_1.stl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]
2024-05-11 Atualizando a versão da simulação ajudantando e controller e inicializando um rviz
    [MAO_v1_1.stl, MAO_v1__1__1.stl, braco_direito_1.stl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]
2024-05-14 Adicionando pluguin da camera e um mundo de futebol
    [camera.xacro, controller.yaml, martha.xacro]
2024-05-18 Algumas correções
    Correção do pe do modelo
    Correção de parametros do PID
    Adição de Kp e Kd no gazebo
    [controller.yaml, martha.xacro, pe_direito_1.stl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]
2024-06-03 Alterando o arquivo para usar a camera como um macro
    [camera.xacro]
2024-06-03 Usando a camera e o imu como macro
    [martha.xacro]
2024-06-03 Criando o macro do IMU
    [IMU.xacro]
2024-06-15 Adicionado juntas revolute ao URDF do robô
    [martha.xacro]
2024-07-19 updating kick algorithm
    [ball.sdf, goal.sdf]
2024-07-28 Change joints from continuous to revolute
    [martha.xacro]
2024-08-01 Adicao de controle
    Adicionado pacote martha_controller.
    Nele há 2 scripts: imu_to_angle.py que é uma tentativa de estabilizar a martha mudando a inclinacao do CG e o giro_braco.py que serve como exemplo de implementacao de codigo usando python e ros
    [martha.xacro]
2024-09-18 modularizing and adding kinematics
2024-10-01 Fazendo ela ficar parada e colocando uma bola
    [martha.xacro, model-1_4.sdf, model.sdf]
